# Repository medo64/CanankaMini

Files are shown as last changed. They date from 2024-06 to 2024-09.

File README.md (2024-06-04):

[Cananka Mini](https://medo64.com/cananka/)
===========================================

Cananka Mini is a minimalistic device connecting to CAN bus using USB serial
port (SLCAN compatible). It has USB type-A connector on computer side and 3.81
mm strip headers on CAN bus side.

The following hardware version are also available:
* [Full](https://github.com/medo64/Cananka) (isolated and in the case)
* [Framework Expansion Card](https://github.com/medo64/CanankaFEC) (non-isolated, in framework expansion card format)
* [HAT](https://github.com/medo64/CanankaHAT) (intended for Raspberry Pi)

The following additional repositories might be of interest:
* [Firmware](https://github.com/medo64/Cananka.Firmware)
* [Protocol](https://github.com/medo64/Cananka.Firmware/blob/main/PROTOCOL.md)
* [Test software](https://github.com/medo64/Cananka.Software)

---

*You can check my blog and other projects at [www.medo64.com](https://medo64.com/cananka/mini/)*

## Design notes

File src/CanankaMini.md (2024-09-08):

### CanankaMini

#### Parts

|  # | Part | RefDes  | Preferred Part Number |
|---:|---|---|---|
|  2 | C 100nF X7R 16V (0805) | C1-C2 | 478-5311-1-ND |
|  1 | C 330nF X7R 16V (0805) | C3 | 732-7669-1-ND |
|  2 | C 10uF X5R 16V (0805) | C4-C5 | 1276-1096-1-ND |
|  2 | DS LED (0805) | DS1-DS2 | 475-1415-1-ND |
|  1 | J USB A, plug, horizontal | J1 | WM3983CT-ND |
|  1 | J MC 1,5/ 4-G-3,81 | J2 | ED2810-ND |
|  1 | L Ferrite 40Ohm (0805) | L1 | 445-2201-1-ND |
|  2 | Q MOSFET P 4.3A 30V ±25Vgs [DMP3056L-7] (SOT23-3)  | Q1-Q2 | DMP3056L-7DICT-ND |
|  2 | R 59 1% 0.25W (0805) | R1-R2 | 2019-RK73H2ATTD59R0FCT-ND  |
|  3 | R 1K 1% 0.125W (0805) | R3-R5 | RMCF0805FT1K00CT-ND |
|  1 | U MCP2221A (TSSOP-14) | U1 | MCP2221A-I/ST-ND |
|  1 | U PIC18F25K80 (SSOP-28) | U2 | PIC18F25K80-I/SS-ND |
|  1 | U MCP2561 (SOIC-8) | U3 | MCP2561-E/SN-ND |
|  1 | P MC 1,5/ 4-ST-3,81 | P2 | ED2877-ND |

1/2" heat-shrink tubing, 41mm

WARNING: This is a non-isolated board - beware of ground loops and all the fun
that can happen with different ground potentials.

#### Specifications

| Property | Value |
|---|---|
| PCB size | 46.5 x 16.5 mm ~ 1.2 sqin  |
| Voltage (in)  | 5 V ±10% |
| Current (in)  | 100 mA (max) |

#### UART Configuration ####

In order to configure the device, one has to use MCP2221 Utility application
(download from Microchip). In configuration, one MUST perform the following
changes:

    * GP1: 1 (CLK_OUT)

The following changes are suggested:

| Property | Value |
|---|---|
| VID: | 0x04D8 |
| PID: | 0xE866 |
| Required Current: | 500 mA |
| Descriptor: | Cananka Mini |
| Manufacturer: | Medo64 |
| Enumerate with serial number | Yes |
| GP1 | CLK_OUT |

All other settings should remain default.

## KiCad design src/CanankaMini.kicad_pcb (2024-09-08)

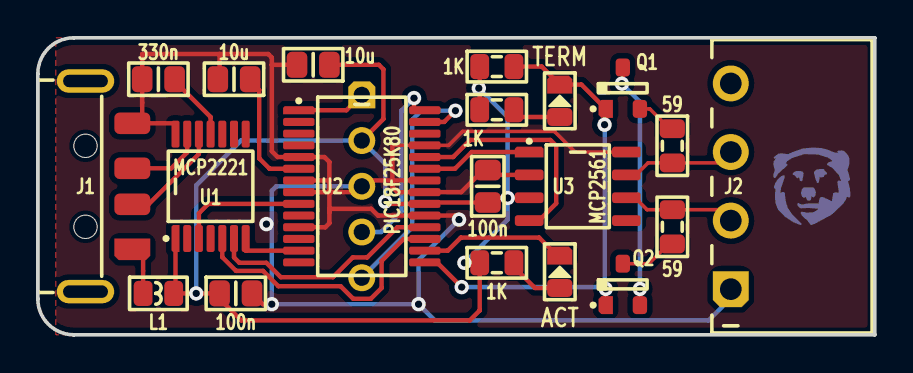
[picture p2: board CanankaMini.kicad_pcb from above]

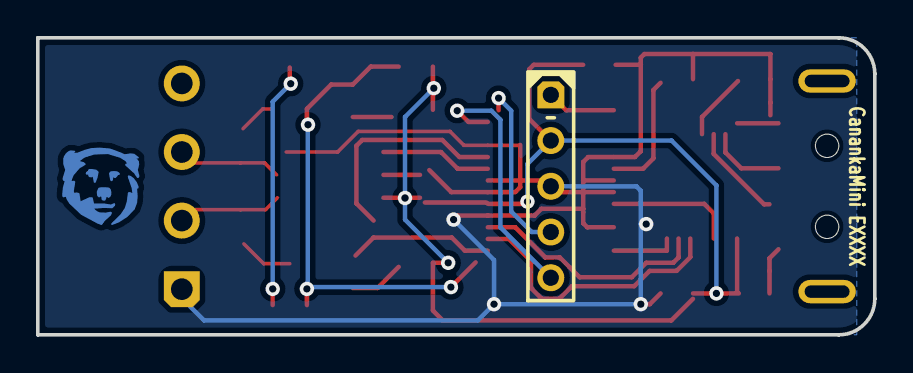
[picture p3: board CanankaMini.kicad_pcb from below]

Board: 2 copper layers, 46.5 x 16.5 mm, 22 parts (2 on the bottom side), 25 nets.

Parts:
C1, C2: 100n; C (0805)
C3: 330n; C (0805)
C4, C5: 10u; C (0805)
DS1: ACT; DS (0805)
DS2: TERM; DS (0805)
ICON: Medo64; ICON Medo64
ICSP: Microchip PIC; ICSP PIC Pogo SS (5w)
J1: 48037-2200; J USB A 2.0 Plug (4w)
J2: MC 1,5/4; J Phoenix MC [CAN] (4w)
L1: 40R; L Ferrite (0805)
Q1, Q2: DMP3056L-7; Q MOSFET-P (SOT23-3)
R1, R2: 59; R (0805)
R3, R4, R5: 1K; R (0805)
U1: MCP2221; U Transceiver UART+I2C [MCP2221] (TSSOP-14)
U2: PIC18F25K80; U Micro [PIC18F25K80] (SSOP-28)
U3: MCP2561; U Transceiver CAN [MCP2561] (SOIC-8)

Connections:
5V: C1.1, C2.1, C5.1, ICSP.2, L1.2, R3.1, R4.1, R5.1, U1.1, U2.20, U3.3
CAN_H: J2.3, R1.2, U3.7
CAN_H_TERM: Q1.2, R1.1
CAN_I_TERM: Q1.3, Q2.2
CAN_L: J2.2, R2.2, U3.6
CAN_L_TERM: Q2.3, R2.1
CAN_RX: U2.24, U3.4
CAN_TX: U2.23, U3.1
GND: C1.2, C2.2, C3.2, C4.2, C5.2, ICSP.3, J1.4, J2.1, U1.14, U2.5, U2.7, U2.8, U2.11, U2.19, U2.21, U2.22, U2.25, U3.2, U3.8
ICSP_PGC: ICSP.5, U2.27
ICSP_PGD: ICSP.4, U2.28
ICSP_VPP: ICSP.1, U2.1
IO_CONTROL_TERMINATE#: DS2.1, Q1.1, Q2.1, R5.2, U2.15
IO_LED_ACTIVITY#: DS1.1, U2.16
IO_USBCFG: U1.7, U2.13
LED_ACTIVITY: DS1.2, R3.2
LED_CAN_TERMINATE: DS2.2, R4.2
OSC: U1.3, U2.9
UART_RX: U1.6, U2.18
UART_TX: U1.5, U2.17
USB_5V: J1.1, L1.1
USB_DM: J1.2, U1.12
USB_DP: J1.3, U1.13
V_CORE: C4.1, U2.6
V_USB: C3.1, U1.11

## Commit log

2024-06-04 Initial KiCAD version
    [CanankaMini.kicad_pcb]
2024-06-05 Added current limiting
    [CanankaMini.kicad_pcb]
2024-06-05 Adjusted current limiting
    [CanankaMini.kicad_pcb]
2024-06-05 Fixing up component list
    [CanankaMini.kicad_pcb]
2024-06-06 Moved designators a bit
    [CanankaMini.kicad_pcb]
2024-06-06 Updated flood fill
    [CanankaMini.kicad_pcb]
2024-09-03 Removing power-on circuit
    [CanankaMini.kicad_pcb]
2024-09-06 Fixing termination circuit
    [CanankaMini.kicad_pcb]
2024-09-06 Swapped mosfet for a more resilient one
    [CanankaMini.kicad_pcb]
2024-09-08 Fixing termination MOSFET connections
    [CanankaMini.kicad_pcb]
